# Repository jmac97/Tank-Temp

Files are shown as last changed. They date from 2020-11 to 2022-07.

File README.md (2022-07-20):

# Tank-Temp

I wanted to make another version of my previous Aquarium Bot project due to the WiFi issues and also wanted a project to get comfortable with the STM32 microcontroller. I developed the system with an STM32 development board and created a "hat" that monitored the temperature, displayed the information on an OLED screen, and alerted my friend via an LED. Detailed description [here](https://www.juliesongmceldoon.com/tank-temp).

<p align="center">
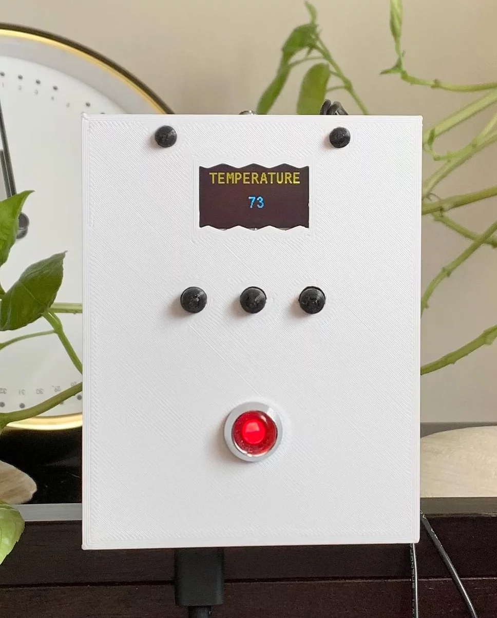
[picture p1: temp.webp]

</p>

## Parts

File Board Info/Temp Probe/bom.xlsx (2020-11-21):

Ref Des | Part Number | Value
C1, C2, C3 |  | .1 uF
D1 | have | Red LED
J1 | have | Connector Pinheader 2.54mm 1x6 Male
J2, J3 | have | Connector Pinheader 2.54mm 1x8 Male
J4 | have | Connector Pinheader 2.54mm 1x10 Male
R1 |  | 10k
R2 |  | 100
R3, R4 |  | 4.7K
SW1A, SW2A, SW3A | have | Tactile switch
TH1 | have | Thermistor
U1A | 24LC01B | I2C EEPROM
U2 | OPA340NA | Op amp
U3A | have_SSD1306 | OLED driver and display

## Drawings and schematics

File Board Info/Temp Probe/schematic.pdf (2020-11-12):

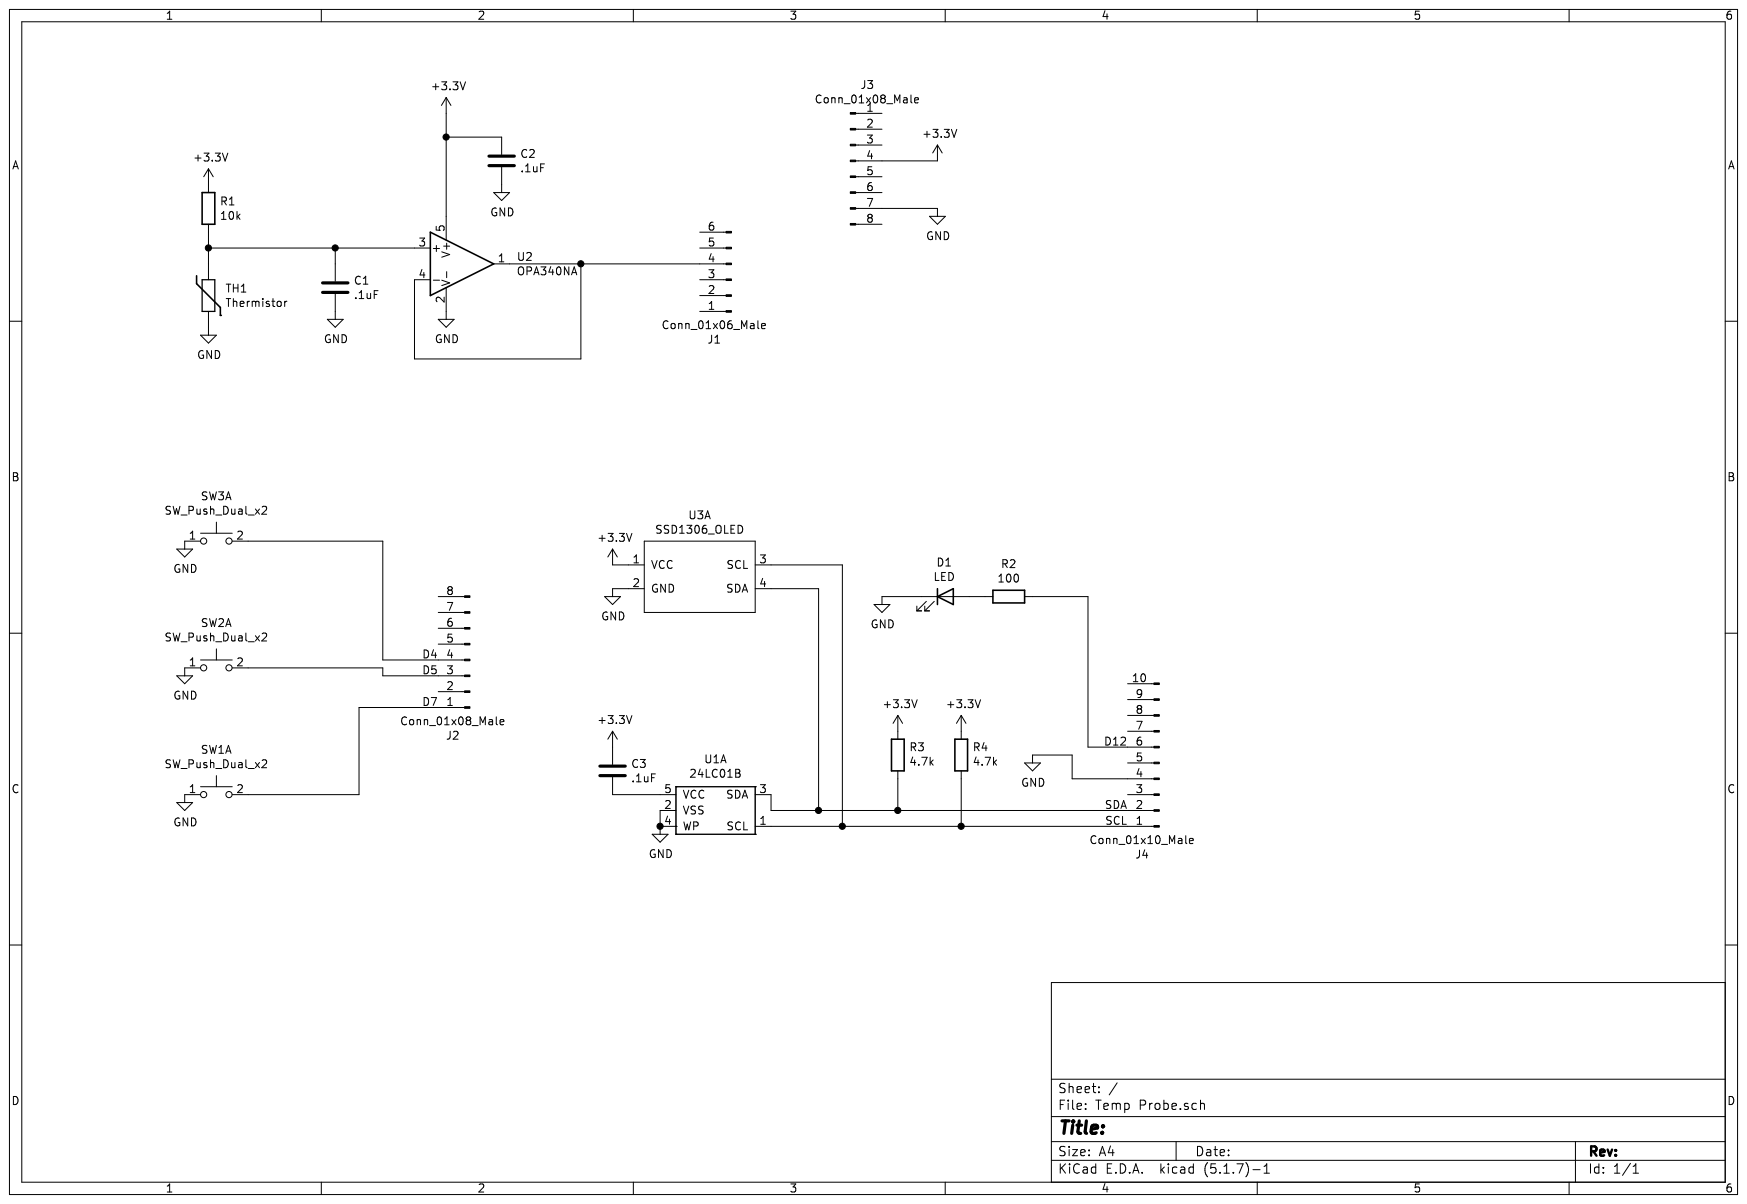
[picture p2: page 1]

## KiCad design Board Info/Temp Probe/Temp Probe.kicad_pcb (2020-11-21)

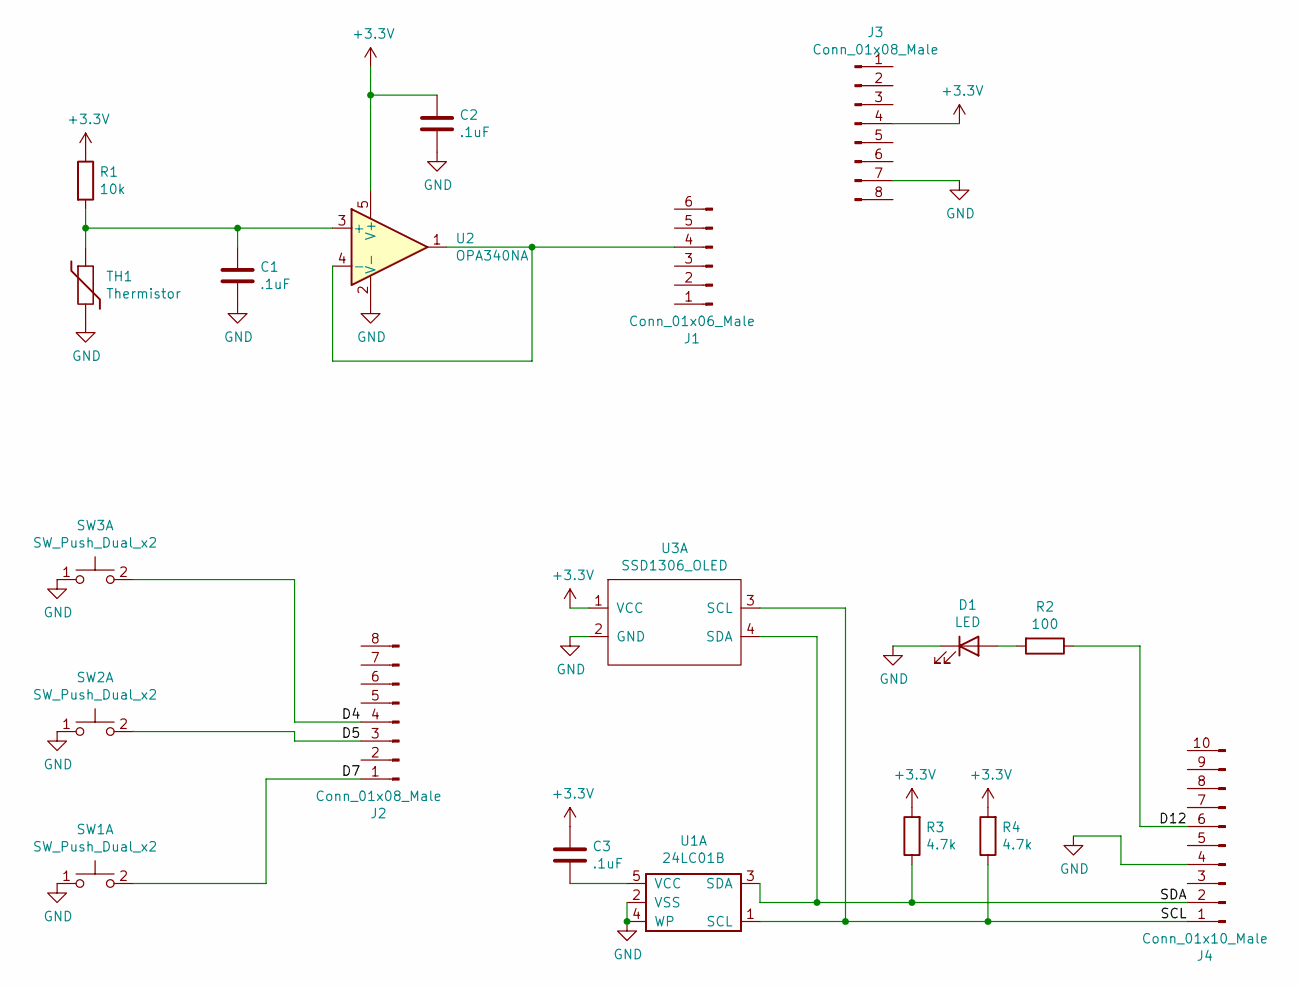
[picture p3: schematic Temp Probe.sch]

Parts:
C1, C2, C3: .1uF; C_0805_2012Metric
D1: LED; PinSocket_1x02_P2.54mm_Vertical
J1: Conn_01x06_Male; PinHeader_1x06_P2.54mm_Vertical
J2, J3: Conn_01x08_Male; PinHeader_1x08_P2.54mm_Vertical
J4: Conn_01x10_Male; PinHeader_1x10_P2.54mm_Vertical
R1: 10k; R_0805_2012Metric_Pad1.20x1.40mm_HandSolder
R2: 100; R_0805_2012Metric
R3, R4: 4.7k; R_0805_2012Metric
SW1, SW2, SW3: SW_Push_Dual_x2; SW_PUSH_6mm_H5mm
TH1: Thermistor; TerminalBlock_Phoenix_MPT-0,5-2-2.54_1x02_P2.54mm_Horizontal
U1: 24LC01B; SOT-23-5
U2: OPA340NA; SOT-23-5
U3: SSD1306_OLED; PinSocket_1x04_P2.54mm_Vertical

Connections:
+3V3: C2.1, C3.1, J3.4, R1.1, R3.2, R4.2, U2.5 (V+), U3.1 (VCC)
/D4: J2.4, SW3.2 (D)
/D5: J2.3, SW2.2 (D)
/D7: J2.1, SW1.2 (D)
/D12: J4.6, R2.1
/SCL: J4.1, R4.1, U1.1 (SCL), U3.3 (SCL)
/SDA: J4.2, R3.1, U1.3 (SDA), U3.4 (SDA)
GND: C1.2, C2.2, D1.1 (K), J3.7, J4.4, SW1.1 (C), SW2.1 (C), SW3.1 (C), TH1.2, U1.2 (VSS), U1.4 (WP), U2.2 (V-), U3.2 (GND)
unnamed: C1.1, R1.2, TH1.1, U2.3 (+)
unnamed: C3.2, U1.5 (VCC)
unnamed: D1.2 (A), R2.2
unnamed: J1.4, U2.1, U2.4 (-)

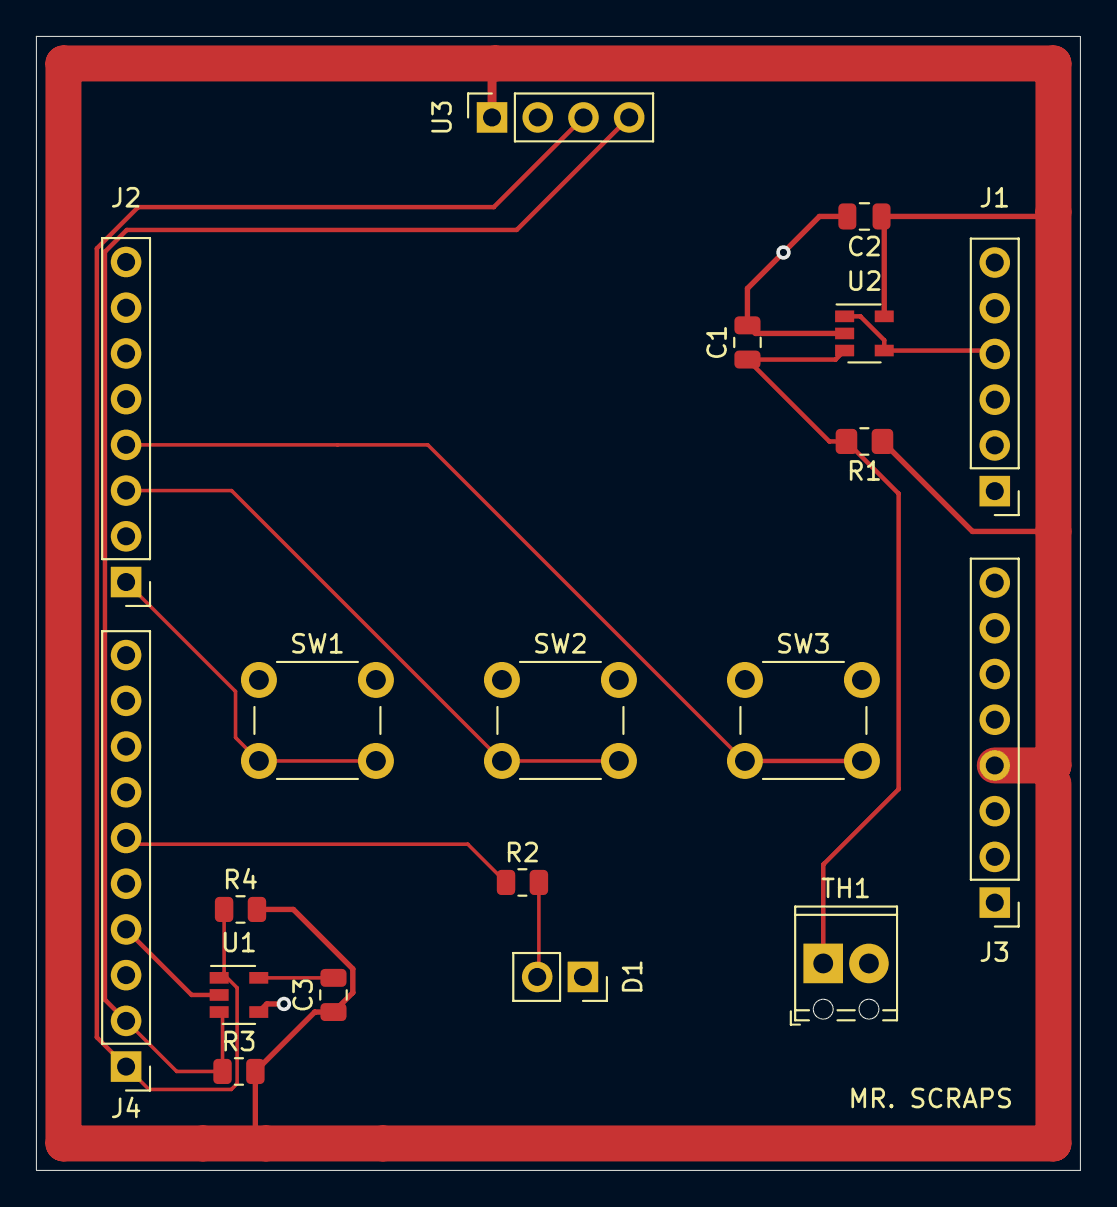
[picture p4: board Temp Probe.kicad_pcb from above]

Board: 2 copper layers, 58.0 x 63.0 mm, 19 parts (0 on the bottom side), 12 nets.

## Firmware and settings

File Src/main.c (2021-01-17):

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

/* Includes ------------------------------------------------------------------*/
#include "main.h"

/* USER CODE BEGIN Includes */
#include <stdio.h>
#include "SSD1306\oled\inc\fonts.h"
#include "SSD1306\oled\inc\ssd1306.h"
#include "ux_manager.h"
#include "thermistor.h"


/* USER CODE END Includes */

/* USER CODE BEGIN PD */
#define BUTTON_PRESSED keyCode != 0xF

/* USER CODE END PD */

ADC_HandleTypeDef hadc1;

I2C_HandleTypeDef hi2c1;

/* USER CODE BEGIN PV */
// flags
extern uint8_t oneMSFlag;
extern uint8_t fiveMSFlag;
extern uint8_t tenMSFlag;
extern uint8_t fiftyMSFlag;
extern uint8_t hundredMSFlag;

// button stuff
uint8_t buttonDebounced = false;
uint8_t buttonProcessed = false;
uint8_t keyCode = 0x0;
int volatile counter = 0;

// temp stuff
uint16_t thermCounts;
int16_t tempC = 0;
int16_t tempF = 0;

// memory 
typedef union _temp_settings {
  uint8_t Array[4];
  struct settingsStruct {
    uint8_t minTemp;
    uint8_t maxTemp;
    uint8_t dummy;
  } settingsData;
} settings;

typedef union _my_union {
  uint8_t Array[6];
  struct _myStruct {
    uint16_t tcCal;
    int16_t cjCal;
    uint8_t valid;
    uint8_t dummy;
  } calData;
} cal_constants;
cal_constants myCalibration;

#define EEPROM_ADDR 0xA0
uint8_t memTxData[4] = {0,0,0,0};
uint8_t memRxData[4] = {0,0,0,0};
HAL_StatusTypeDef i2cResult = HAL_OK;

settings userSettings;


/* USER CODE END PV */

void SystemClock_Config(void);
static void MX_GPIO_Init(void);
static void MX_ADC1_Init(void);
static void MX_I2C1_Init(void);
/**
  * @brief  The application entry point.
  * @retval int
  */
int main(void)
{
  /* MCU Configuration--------------------------------------------------------*/

  /* Reset of all peripherals, Initializes the Flash interface and the Systick. */
  HAL_Init();

  /* Configure the system clock */
  SystemClock_Config();

  /* Initialize all configured peripherals */
  MX_GPIO_Init();
  MX_ADC1_Init();
  MX_I2C1_Init();
  /* USER CODE BEGIN 2 */

  SSD1306_Init();
  SwitchScreens(HOME);
  HAL_Delay (1000);
  
  myCalibration.calData.cjCal = 23;
  myCalibration.calData.tcCal = -137;
  myCalibration.calData.valid = true;
 
 i2cResult = HAL_I2C_Mem_Write(&hi2c1, EEPROM_ADDR, 0, I2C_MEMADD_SIZE_8BIT, myCalibration.Array, 6, 1000);
 
 i2cResult = HAL_I2C_Mem_Read(&hi2c1, EEPROM_ADDR, 0, I2C_MEMADD_SIZE_8BIT, memRxData, 4, 1000);
  
  userSettings.settingsData.minTemp = 76;
  userSettings.settingsData.maxTemp = 80;
  
  memTxData[0] = 3;
  memTxData[1] = 2;
  memTxData[2] = 1;
  memTxData[3] = 0;
  
  i2cResult = HAL_I2C_Mem_Write(&hi2c1, EEPROM_ADDR, 0, I2C_MEMADD_SIZE_8BIT, memTxData, 4, 1000);
  
  HAL_Delay(500);
  
  memRxData[0] = 0xFF;
  memRxData[1] = 0xFF;
  memRxData[2] = 0xFF;
  memRxData[3] = 0xFF;
   
  i2cResult = HAL_I2C_Mem_Read(&hi2c1, EEPROM_ADDR, 0, I2C_MEMADD_SIZE_8BIT, memRxData, 4, 1000);
  
  

  /* USER CODE END 2 */

  /* Infinite loop */
  /* USER CODE BEGIN WHILE */
  while (1)
  {    
    if (hundredMSFlag) {
      hundredMSFlag = false;
      HAL_ADC_Start_IT(&hadc1);
      
      keyCode = GetButtonVal();
      if(BUTTON_PRESSED) {
        if (buttonDebounced == true) {
            buttonProcessed = ProcessKeyCode(keyCode);
          }
        else {
          buttonDebounced = true;
        }
      }
      else {
          buttonDebounced = false;
      }
    }
    
    if (oneMSFlag) {
      oneMSFlag = false;
      
      tempC = ThermTemp(thermCounts);
      tempF = C2F(tempC);
      tempInF.data = tempF;
      
      if ((tempF >= maxTemp.data) || (tempF <= minTemp.data)) {
        HAL_GPIO_WritePin(GPIOA, GPIO_PIN_6, GPIO_PIN_SET);
      } else {
        HAL_GPIO_WritePin(GPIOA, GPIO_PIN_6, GPIO_PIN_RESET);
      }
      
      UpdateScreen();
    }
    
  
    /* USER CODE END WHILE */

    /* USER CODE BEGIN 3 */
  }
  /* USER CODE END 3 */
}

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


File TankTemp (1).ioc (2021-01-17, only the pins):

Mcu.UserName=STM32G070RBTx
PA6.Signal=GPIO_Output
PA8.Signal=GPIO_Input
PB1.Signal=ADC1_IN9
PB14.Signal=GPIO_Output
PB4.Signal=GPIO_Input
PB5.Signal=GPIO_Input
PB8.Signal=I2C1_SCL
PB9.Signal=I2C1_SDA
PC13.Signal=GPIO_Input

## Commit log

2020-11-11 board and schematic
2020-11-12 gerber and drill info
    [Temp Probe-B_Cu.gbr, Temp Probe-B_Mask.gbr, Temp Probe-B_Paste.gbr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]
2020-11-21 BOARD STUFF
    [Temp Probe-B_Cu.gbr, Temp Probe-B_Mask.gbr, Temp Probe-B_Paste.gbr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]

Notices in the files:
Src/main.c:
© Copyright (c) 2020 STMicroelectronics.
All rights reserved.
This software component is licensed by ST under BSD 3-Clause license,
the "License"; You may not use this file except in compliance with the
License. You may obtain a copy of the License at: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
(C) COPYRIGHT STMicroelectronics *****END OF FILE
